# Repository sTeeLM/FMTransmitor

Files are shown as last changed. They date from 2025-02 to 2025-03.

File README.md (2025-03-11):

# FM发射器

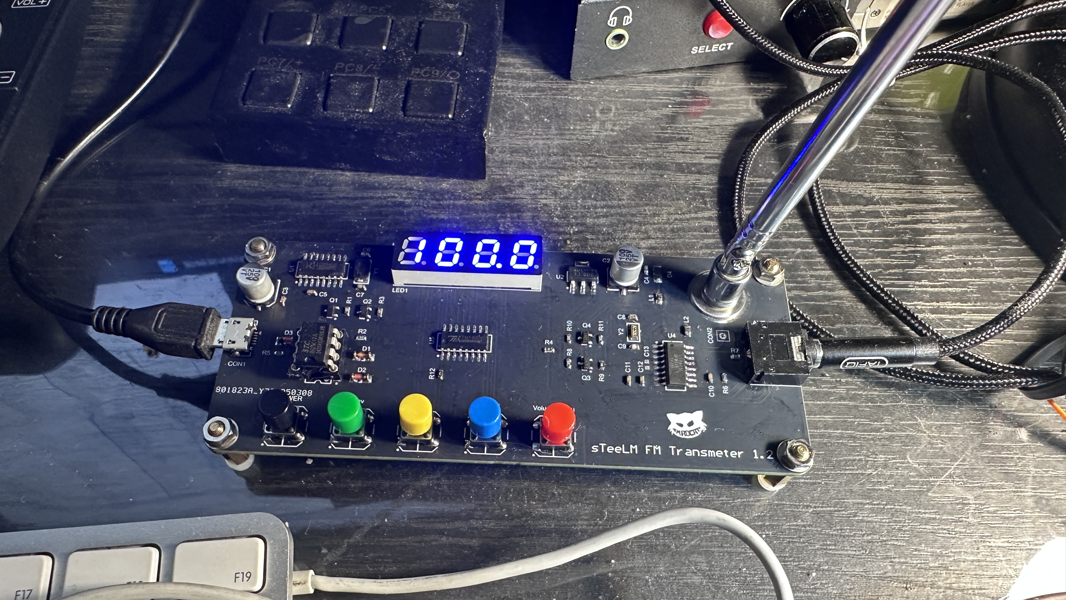
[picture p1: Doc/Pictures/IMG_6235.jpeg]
前脸
 

## 有什么用
将音频输入通过FM调制出去，频率范围70~108MHz。  
我工作台上有个德生的收音机，有了这个装置，可以把收音机变为一个外放喇叭，这样就省了一个外置音响。
另外老实的车上只有收音机的话，可以用这个装置将MP3外放到收音机上。

## 功能
1. 频率调节：70~108MHz步长0.1MHz。
2. 常用功能：调节音量、静音、显示亮度。
3. 高级功能：ALC(Automatic Level Control)等等。

## 设计细节
1. FM射频芯片使用KT0803L，功能比较丰富，基本都在单片机上做了配置项。
2. LED数码管控制芯片使用TM1650，充分解放了单片机，而且实现了按键自由。
3. 主控还是使用STC8G，并且在本制作中没有用外置ROM，而是使用了单片机自带的EEROM。
4. 由于LED使用蓝色数码管，需要5V驱动，而FM芯片需要3.3V工作电压，需要一个I2C的电平转化逻辑。
5. PCB注意数字地平面和模拟地平面分开，并且单点连通。

## What is it used for?
It modulates audio input through FM transmission, with a frequency range of 70~108MHz.  
I have a Tecsun radio on my workbench, and with this device, the radio can be turned into an external speaker, saving the need for an external sound system.
Additionally, if an older car only has a radio, this device can be used to play MP3s through the car's radio.

## Features
1. **Frequency adjustment**: 70~108MHz step with 0.1MHz.
2. **Common functions**: Volume adjustment, mute, display brightness.
3. **Advanced functions**: ALC (Automatic Level Control), etc.

## Design Details
1. The FM radio frequency chip uses **KT0803L**, which is quite feature-rich, with most configurations exported as config with the microcontroller.
2. The LED digital tube control chip uses **TM1650**, which fully free the microcontroller from led scan and key scan logic.
3. The microcontroller still uses **STC8G**, no external ROM is used; instead, the microcontroller's built-in EEROM is utilized.
4. Since the LED uses a blue digital tube that requires **5V** to drive, and the FM chip requires a **3.3V** operating voltage, an **I2C level conversion logic** is needed.
5. The PCB design ensures that the **digital ground plane** and **analog ground plane** are separated and connected at a single point.

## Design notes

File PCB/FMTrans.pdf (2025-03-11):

Line # | Designator | Name | Description | Value | Quantity
| C1, C2 | Cap Pol1 | Polarized Capacitor (Radial) | 100uF,25V | 2
| C3, C4, C5, C10, C11, C12, C13 | Cap | Capacitor | 104 | 7
| C6, C7 | Cap | Capacitor | 220 | 2
| C8, C9 | Cap | Capacitor | 150 | 2
| CON1 | USB-mrico | | | 1
| CON2 | ANT | ANT | | 1
| CON3 | HEADPHONE_3.5 | HEADPHONE_3.5 | | 1
| D1, D2, D3 | 1N4148 | 1N4148 | | 3
| D4 | M4 | 1N4148 | | 1
| L1 | Inductor | Inductor | 30R | 1
| L2 | Inductor | Inductor | 120nH | 1
| LED1 | HSN2481 | HSN2481 | | 1
| Q1 | AO3401,A19T | P-Channel Power MOSFET | | 1
| Q2, Q3, Q4 | AO3400,A09T | N-Channel Power MOSFET | | 3
| R1, R3 | Res2 | Resistor | 3M | 2
| R2, R7, R8, R9, R10, R11 | Res2 | Resistor | 10K | 6
| R4 | Res2 | Resistor | 0R | 1
| R5 | Res2 | Resistor | 300R | 1
| R6 | Res2 | Resistor | 1K | 1
| R12 | Res2 | Resistor | 2K | 1
| SW1 | SW | SW | | 1
| SW2 | NEG | SW | | 1
| SW3 | PLUS | SW | | 1
| SW4 | OK | SW | | 1
| SW5 | MENU | SW | | 1
| U1 | CH340G | CH340G | | 1
| U2 | AMS1117 | AMS1117 | | 1
| U3 | STC8G1K17A | STC8G1K17A | | 1
| U4 | KT0803L | KT0803L | | 1
| U5 | TM1650 | TM1650 | | 1
| Y1 | 12M | Crystal Oscillator | | 1
| Y2 | 32.768K | Crystal Oscillator | | 1

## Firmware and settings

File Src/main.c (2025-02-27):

#include <STC8G.H>

#include "debug.h"
#include "gpio.h"
#include "power.h"
#include "com.h"
#include "eerom.h"
#include "delay.h"
#include "task.h"
#include "clock.h"
#include "button.h"
#include "power.h"
#include "tm1650.h"
#include "kt0803.h"
#include "sm.h"
#include "task.h"

void main(void)
{
  uint8_t i = '-';
  
  EA = 1;
  
  debug_initialize();
  gpio_initialize();
  com_initialize();
  power_initialize();
  power_set_enable(1);
  
  tm1650_initialize(); 
  
  eerom_initialize();
  tm1650_set_brightness(tm1650_cfg.brightness);
  
  kt0803_initialize();
  
  button_initialize();
  clock_initialize();
  task_initialize();
  sm_initialize();
  
  delay_ms(1000);

  while(1) {
    task_run();
  }
 
}

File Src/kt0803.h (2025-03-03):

#ifndef __FM_TRANS_KT0803_H__
#define __FM_TRANS_KT0803_H__

#include <stdint.h>
/*
  SM_TRANS_ALC,       // Automatic Level Control
  SM_TRANS_SD,        // Silence Detection
  SM_TRANS_RF_GAIN,   // RF Gain
  SM_TRANS_PTA,       // Pilot Tone Amplitude
  SM_TRANS_PTC,       // Pre-emphasis Time-Constant
  SM_TRANS_STEREO,    // Stereo or Mono
  SM_TRANS_BASS,      // Bass Boost Control
  SM_TRANS_FDD,       // Frequency Deviation Delection
  SM_TRANS_AFRE,      // Audio Frequency Response Enhancement
  SM_TRANS_SCM,       // Switching Channel Mode Selection
  SM_TRANS_PA         // Power Amplifier
*/

#define KT0803_CFG_FLAG_ALC_ENABLE  0x1
#define KT0803_CFG_FLAG_PDPA        0x2  // Power Amplifier
#define KT0803_CFG_FLAG_PADN        0x4
#define KT0803_CFG_FLAG_PA_BIAS     0x8
#define KT0803_CFG_FLAG_SLNCDIS     0x10
#define KT0803_CFG_FLAG_PLTADJ      0x20  // PTA
#define KT0803_CFG_FLAG_PHTCNST     0x40  // PTC
#define KT0803_CFG_FLAG_MONO        0x80  // Stereo or Mono
#define KT0803_CFG_FLAG_FDD         0x100 // Frequency Deviation Delection
#define KT0803_CFG_FLAG_AFRE        0x200 // Audio Frequency Response Enhancement
#define KT0803_CFG_FLAG_SCM         0x300 // Switching Channel Mode Selection
#define KT0803_CFG_FLAG_MUTE        0x400 // Mute

typedef struct _kt0803_cfg_t
{
  uint16_t flag;
  uint16_t freq;        // Channel
  uint8_t  alc_delay;   // ALC
  uint8_t  alc_attack;
  uint8_t  alc_comp_gain;  
  uint8_t  alc_hold; 
  uint8_t  alc_high_th;
  uint8_t  alc_low_th; 
  uint8_t  slncthl;     // SD
  uint8_t  slncthh;
  uint8_t  slnccnt_high;
  uint8_t  slnccnt_low;
  uint8_t  sln_time;
  uint8_t  rf_gain;     // RF Gain
  int8_t   pga_gain;    // PGA (Volume)
  uint8_t  bass;        // Bass Boost Control
}kt0803_cfg_t;

typedef enum _kt0803_rf_gain_t
{
  KT0803_RF_GAIN_955 = 0,
  KT0803_RF_GAIN_965,
  KT0803_RF_GAIN_975,
  KT0803_RF_GAIN_982,
  KT0803_RF_GAIN_989,  
  KT0803_RF_GAIN_1000, 
  KT0803_RF_GAIN_1015,
  KT0803_RF_GAIN_1028,
  KT0803_RF_GAIN_1051,
  KT0803_RF_GAIN_1056,
  KT0803_RF_GAIN_1062, 
  KT0803_RF_GAIN_1065,
  KT0803_RF_GAIN_1070,
  KT0803_RF_GAIN_1074,
  KT0803_RF_GAIN_1077,
  KT0803_RF_GAIN_1080
}kt0803_rf_gain_t;

typedef enum _kt0803_pltadj_t
{
  KT0803_PLTADJ_LOW = 0,
  KT0803_PLTADJ_HIGH
}kt0803_pltadj_t;

typedef enum _kt0803_phtcnst_t
{
  KT0803_PHTCNST_75US = 0,
  KT0803_PHTCNST_50US
}kt0803_phtcnst_t;

typedef enum _kt0803_bass_t
{
  KT0803_BASS_DISABLE = 0,
  KT0803_BASS_5DB,
  KT0803_BASS_11DB,
  KT0803_BASS_17DB, 
}kt0803_bass_t;

typedef enum _kt0803_pga_mod_t
{
  KT0803_PGA_MOD_4DB_STEP = 0,
  KT0803_PGA_MOD_1DB_STEP
}kt0803_pga_mod_t;

typedef enum _kt0803_alc_delay_t
{
  KT0803_ALC_DELAY_25US = 0,
  KT0803_ALC_DELAY_50US, 
  KT0803_ALC_DELAY_75US, 
  KT0803_ALC_DELAY_100US,
  KT0803_ALC_DELAY_125US,
  KT0803_ALC_DELAY_150US,
  KT0803_ALC_DELAY_175US,
  KT0803_ALC_DELAY_200US,
  KT0803_ALC_DELAY_50MS,
  KT0803_ALC_DELAY_100MS,
  KT0803_ALC_DELAY_150MS,
  KT0803_ALC_DELAY_200MS,
  KT0803_ALC_DELAY_250MS,
  KT0803_ALC_DELAY_300MS,
  KT0803_ALC_DELAY_350MS,
  KT0803_ALC_DELAY_400MS,  
}kt0803_alc_delay_t;

typedef enum _kt0803_alc_attack_t
{
  KT0803_ALC_ATTACK_25US = 0,
  KT0803_ALC_ATTACK_50US, 
  KT0803_ALC_ATTACK_75US, 
  KT0803_ALC_ATTACK_100US,
  KT0803_ALC_ATTACK_125US,
  KT0803_ALC_ATTACK_150US,
  KT0803_ALC_ATTACK_175US,
  KT0803_ALC_ATTACK_200US,
  KT0803_ALC_ATTACK_50MS,
  KT0803_ALC_ATTACK_100MS,
  KT0803_ALC_ATTACK_150MS,
  KT0803_ALC_ATTACK_200MS,
  KT0803_ALC_ATTACK_250MS,
  KT0803_ALC_ATTACK_300MS,
  KT0803_ALC_ATTACK_350MS,
  KT0803_ALC_ATTACK_400MS,  
}kt0803_alc_attack_t;

typedef enum _kt0803_alc_comp_gain_t
{
  KT0803_ALC_COMP_GAIN_N6DB = 0,
  KT0803_ALC_COMP_GAIN_N9DB,
  KT0803_ALC_COMP_GAIN_N12DB,
  KT0803_ALC_COMP_GAIN_N15DB, 
  KT0803_ALC_COMP_GAIN_6DB,
  KT0803_ALC_COMP_GAIN_3DB,
  KT0803_ALC_COMP_GAIN_0DB,
  KT0803_ALC_COMP_GAIN_N3DB, 
}kt0803_alc_comp_gain_t;

typedef enum _kt0803_alc_hold_t
{
  KT0803_ALC_HOLD_50MS = 0,
  KT0803_ALC_HOLD_100MS,
  KT0803_ALC_HOLD_150MS,
  KT0803_ALC_HOLD_200MS,
  KT0803_ALC_HOLD_1S,
  KT0803_ALC_HOLD_5S,
  KT0803_ALC_HOLD_10S,
  KT0803_ALC_HOLD_15S,  
}kt0803_alc_hold_t;

typedef enum _kt0803_alc_high_th_t
{
  KT0803_ALC_HIGH_TH_0P6 = 0,
  KT0803_ALC_HIGH_TH_0P5,
  KT0803_ALC_HIGH_TH_0P4,
  KT0803_ALC_HIGH_TH_0P3,
  KT0803_ALC_HIGH_TH_0P2,
  KT0803_ALC_HIGH_TH_0P1,
  KT0803_ALC_HIGH_TH_0P05,
  KT0803_ALC_HIGH_TH_0P01,  
}kt0803_alc_high_th_t;

typedef enum _kt0803_alc_low_th_t
{
  KT0803_ALC_LOW_TH_0P25 = 0, 
  KT0803_ALC_LOW_TH_0P2,
  KT0803_ALC_LOW_TH_0P15,
  KT0803_ALC_LOW_TH_0P1,
  KT0803_ALC_LOW_TH_0P05,
  KT0803_ALC_LOW_TH_0P03,
  KT0803_ALC_LOW_TH_0P02,
  KT0803_ALC_LOW_TH_0P01,
  KT0803_ALC_LOW_TH_0P005,
  KT0803_ALC_LOW_TH_0P001,
  KT0803_ALC_LOW_TH_0P0005,
  KT0803_ALC_LOW_TH_0P0001,  
}kt0803_alc_low_th_t;

typedef enum _kt0803_slncthl_t
{
  KT0803_SLNCTHL_025MV = 0,
  KT0803_SLNCTHL_050MV,
  KT0803_SLNCTHL_1MV, 
  KT0803_SLNCTHL_2MV,
  KT0803_SLNCTHL_4MV,
  KT0803_SLNCTHL_6MV,
  KT0803_SLNCTHL_8MV,
  KT0803_SLNCTHL_16MV,
  KT0803_SLNCTHL_32MV,  
}kt0803_slncthl_t;

typedef enum _kt0803_slncthh_t
{
  KT0803_SLNCTHH_050MV = 0,
  KT0803_SLNCTHH_1MV, 
  KT0803_SLNCTHH_2MV,
  KT0803_SLNCTHH_4MV,
  KT0803_SLNCTHH_6MV,
  KT0803_SLNCTHH_8MV,
  KT0803_SLNCTHH_16MV,
  KT0803_SLNCTHH_32MV, 
  KT0803_SLNCTHH_64MV,   
}kt0803_slncthh_t;

typedef enum _kt0803_slnccnt_high_t
{
  KT0803_SLNCCNT_HIGH_15 = 0,
  KT0803_SLNCCNT_HIGH_31,
  KT0803_SLNCCNT_HIGH_63,
  KT0803_SLNCCNT_HIGH_127,
  KT0803_SLNCCNT_HIGH_255, 
  KT0803_SLNCCNT_HIGH_511,
  KT0803_SLNCCNT_HIGH_1023,
  KT0803_SLNCCNT_HIGH_2047,  
}kt0803_slnccnt_high_t;

typedef enum _kt0803_slnccnt_low_t
{
  KT0803_SLNCCNT_LOW_1 = 0,
  KT0803_SLNCCNT_LOW_2,
  KT0803_SLNCCNT_LOW_4,
  KT0803_SLNCCNT_LOW_8, 
  KT0803_SLNCCNT_LOW_16,
  KT0803_SLNCCNT_LOW_32,
  KT0803_SLNCCNT_LOW_64,
  KT0803_SLNCCNT_LOW_128, 
}kt0803_slnccnt_low_t;

typedef enum _kt0803_sln_time_t
{
  KT0803_SLN_TIME_50MS = 0,
  KT0803_SLN_TIME_100MS,
  KT0803_SLN_TIME_200MS, 
  KT0803_SLN_TIME_400MS, 
  KT0803_SLN_TIME_1S,
  KT0803_SLN_TIME_2S,
  KT0803_SLN_TIME_4S,
  KT0803_SLN_TIME_8S,
  KT0803_SLN_TIME_16S,
  KT0803_SLN_TIME_32S,
  KT0803_SLN_TIME_40S,
  KT0803_SLN_TIME_48S, 
  KT0803_SLN_TIME_56S,
  KT0803_SLN_TIME_60S,
  KT0803_SLN_TIME_64S,   
}kt0803_sln_time_t;

typedef enum _kt0803_swch_mod_t
{
  KT0803_SWCH_MOD_MUTE = 0,
  KT0803_SWCH_MOD_PA
}kt0803_swch_mod_t;

typedef enum _kt0803_pa_ctl_t
{
  KT0803_PA_CTL_INTERNAL = 0,
  KT0803_PA_CTL_EXTERNAL
}kt0803_pa_ctl_t;

typedef enum _kt0803_ref_clk_t
{
  KT0803_REF_CLK_32768K = 0,
  KT0803_REF_CLK_6P5M,
  KT0803_REF_CLK_7P6M,
  KT0803_REF_CLK_12M, 
  KT0803_REF_CLK_13M,
  KT0803_REF_CLK_15P2M,
  KT0803_REF_CLK_19P2M,
  KT0803_REF_CLK_24M,
  KT0803_REF_CLK_26M,  
}kt0803_ref_clk_t;

typedef enum _kt0803_fedv_t
{
  KT0803_FEDV_75KHZ = 0,
  KT0803_FEDV_112P5KHZ
}kt0803_fedv_t;

extern kt0803_cfg_t kt0803_cfg;

void kt0803_initialize(void);
void kt0803_factory_reset(void);
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

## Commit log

2025-02-21 led and keypad worked！
    [STC8G1K17A-8PIN.cfg]
2025-03-02 all finished！
2025-03-03 almost finish
    [FMTrans.PcbDoc, FMTrans.PrjPcb, FMTrans.SchDoc]
2025-03-08 bugfix
    KT0803工作电压不能大于3.3V，所以直接用AMS1117-3.3带不能正常工作，必须加个二极管把电压降下来一点点。。
    [FMTrans.PcbDoc, FMTrans.PrjPcb, FMTrans.SchDoc]
2025-03-08 pcb bugfix
    把天线馈线加粗了一点点，代码修正了不能保存亮度设置的bug
    [FMTrans.PcbDoc]
2025-03-11 bugfix
    磁珠有点点大，改成30R，不然不能正常工作
    [FMTrans.PcbDoc, FMTrans.SchDoc]
